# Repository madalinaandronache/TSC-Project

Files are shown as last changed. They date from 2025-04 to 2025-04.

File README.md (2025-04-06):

# OpenBook - E-book Reader Open-Source

Student: Andronache Madalina-Georgiana
Grupa: 332CC

Urmatorul fisier contine informatii despre rezolvarea cerintelor
propuse.

Cuprins:

0. Descrierea cerintelor
1. Diagrama bloc
2. BOM - Bill of Materials
3. Functionalitatea hardware
4. Pini utilizați pe ESP32-C6 și justificare
5. Observatii

## 0. Descrierea cerintelor

OpenBook este un e-book reader open-source, conceput să fie ieftin, compact și ușor de produs. 
Acest proiect este realizat în cadrul unui start-up educațional, iar scopul este dezvoltarea unui 
dispozitiv complet funcțional, pornind de la specificațiile sistemului până la fișierele de fabricație.

## 1. Diagrama bloc

Hardware Diagram

## 2. BOM - Bill of Materials

| Device | Value | Check_Price | Datasheet |
|---|---|---|---|
| ADAFRUIT_LEDCHIP-LED0603 | - | [Link](https://www.snapeda.com/parts/KP-1608SURCK/Kingbright/view-part/?ref=search&t=LED%200603) | [Link](https://www.snapeda.com/parts/KP-1608SURCK/Kingbright/datasheet/) |
| SJ | - | [Link](https://grabcad.com/library/solder-jumpers-1) | - |
| EAGLE-LTSPICE_C | 0.1uF/50V | [Link](https://componentsearchengine.com/part-view/CC0402MRX5R5BB106/YAGEO) | [Link](https://componentsearchengine.com/Datasheets/2/CC0402MRX5R5BB106.pdf) |
| ESP32_WROVER_EAGLE-LTSPICE_R | 0.47 | [Link](https://componentsearchengine.com/part-view/R0402%201%25%20100%20K%20(RC0402FR-07100KL)/YAGEO) | [Link](https://www.yageo.com/upload/media/product/products/datasheet/rchip/PYu-RC_Group_51_RoHS_L_12.pdf) |
| ESP32_WROVER_EAGLE-LTSPICE_R | 100K | [Link](https://componentsearchengine.com/part-view/R0402%201%25%20100%20K%20(RC0402FR-07100KL)/YAGEO) | [Link](https://www.yageo.com/upload/media/product/products/datasheet/rchip/PYu-RC_Group_51_RoHS_L_12.pdf) |
| EAGLE-LTSPICE_C | 100nF | [Link](https://componentsearchengine.com/part-view/CC0402MRX5R5BB106/YAGEO) | [Link](https://componentsearchengine.com/Datasheets/2/CC0402MRX5R5BB106.pdf) |
| RCL_CPOL-EUCT3528 | 100uF TANT | [Link](https://www.snapeda.com/parts/TAJB475K025RNJ/AVX/view-part/?ref=dk&t=capacitor%203528&con_ref=None) | [Link](https://s3.amazonaws.com/snapeda/datasheet/TAJB475K025RNJ_AVX.pdf) |
| ESP32_WROVER_EAGLE-LTSPICE_R | 10K | [Link](https://componentsearchengine.com/part-view/R0402%201%25%20100%20K%20(RC0402FR-07100KL)/YAGEO) | [Link](https://www.yageo.com/upload/media/product/products/datasheet/rchip/PYu-RC_Group_51_RoHS_L_12.pdf) |
| EAGLE-LTSPICE_C | 10uF | [Link](https://componentsearchengine.com/part-view/CC0402MRX5R5BB106/YAGEO) | [Link](https://componentsearchengine.com/Datasheets/2/CC0402MRX5R5BB106.pdf) |
| 112A-TAAR-R03_ATTEND | 112A-TAAR-R03_ATTEND | [Link](https://store.comet.srl.ro/Catalogue/Product/43497/) | [Link](https://store.comet.bg/download-file.php?id=8824) |
| ESP32_WROVER_EAGLE-LTSPICE_R | 15 | [Link](https://componentsearchengine.com/part-view/R0402%201%25%20100%20K%20(RC0402FR-07100KL)/YAGEO) | [Link](https://www.yageo.com/upload/media/product/products/datasheet/rchip/PYu-RC_Group_51_RoHS_L_12.pdf) |
| EAGLE-LTSPICE_C | 1uF | [Link](https://componentsearchengine.com/part-view/CC0402MRX5R5BB106/YAGEO) | [Link](https://componentsearchengine.com/Datasheets/2/CC0402MRX5R5BB106.pdf) |
| EAGLE-LTSPICE_C | 1uF/50V | [Link](https://componentsearchengine.com/part-view/CC0402MRX5R5BB106/YAGEO) | [Link](https://componentsearchengine.com/Datasheets/2/CC0402MRX5R5BB106.pdf) |
| ESP32_WROVER_EAGLE-LTSPICE_R | 2.2 | [Link](https://componentsearchengine.com/part-view/R0402%201%25%20100%20K%20(RC0402FR-07100KL)/YAGEO) | [Link](https://www.yageo.com/upload/media/product/products/datasheet/rchip/PYu-RC_Group_51_RoHS_L_12.pdf) |
| ESP32_WROVER_EAGLE-LTSPICE_R | 200 | [Link](https://componentsearchengine.com/part-view/R0402%201%25%20100%20K%20(RC0402FR-07100KL)/YAGEO) | [Link](https://www.yageo.com/upload/media/product/products/datasheet/rchip/PYu-RC_Group_51_RoHS_L_12.pdf) |
| ESP32_WROVER_SPARKFUN-DISCRETESEMI_MOSFET_PCH-DMG2305UX-7 | 20V/4.2A/52m?/1.4W | [Link](https://componentsearchengine.com/part-view/DMG2305UX-7/Diodes%20Incorporated) | [Link](https://www.diodes.com//assets/Datasheets/DMG2305UX.pdf) |
| ESP32_WROVER_EAGLE-LTSPICE_R | 2K | [Link](https://componentsearchengine.com/part-view/R0402%201%25%20100%20K%20(RC0402FR-07100KL)/YAGEO) | [Link](https://www.yageo.com/upload/media/product/products/datasheet/rchip/PYu-RC_Group_51_RoHS_L_12.pdf) |
| EAGLE-LTSPICE_C | 4.7uF | [Link](https://componentsearchengine.com/part-view/CC0402MRX5R5BB106/YAGEO) | [Link](https://componentsearchengine.com/Datasheets/2/CC0402MRX5R5BB106.pdf) |
| EAGLE-LTSPICE_C | 4.7uF/25V | [Link](https://componentsearchengine.com/part-view/CC0402MRX5R5BB106/YAGEO) | [Link](https://componentsearchengine.com/Datasheets/2/CC0402MRX5R5BB106.pdf) |
| ESP32_WROVER_EAGLE-LTSPICE_R | 5k1 | [Link](https://componentsearchengine.com/part-view/R0402%201%25%20100%20K%20(RC0402FR-07100KL)/YAGEO) | [Link](https://www.yageo.com/upload/media/product/products/datasheet/rchip/PYu-RC_Group_51_RoHS_L_12.pdf) |
| 744043680IND_4828-WE-TPC_WRE | 68uH | [Link](https://ro.mouser.com/ProductDetail/Wurth-Elektronik/744043680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.) | [Link](https://www.we-online.com/components/products/datasheet/744043680.pdf) |
| BD5229G-TR | BD5229G-TR | [Link](https://componentsearchengine.com/part-view/BD5229G-TR/ROHM%20Semiconductor) | [Link](https://datasheet.datasheetarchive.com/originals/distributors/Datasheets_SAMA/f2b9741ef86007909f138d561a359946.pdf) |
| ESP32_WROVER_BME680_BME680 | BME688 | [Link](https://www.snapeda.com/parts/BME680/Bosch/view-part/?welcome=home) | [Link](https://www.snapeda.com/parts/BME680/Bosch%20Sensortec/datasheet/) |
| BUTTON_CUSYOMV1V2 | BUTTON_CUSYOMV1V2 | [Link](https://industry.panasonic.com/global/en/products/control/switch/light-touch/number/evqpuj02k) | [Link](https://industry.panasonic.com/global/en/downloads?tab=catalog&small_g_cd=203&part_no=EVQPUJ02K) |
| CPH3225A | CPH3225A | [Link](https://www.snapeda.com/parts/CPH3225A/Seiko+Instruments/view-part/?ref=eda) | [Link](https://www.snapeda.com/parts/CPH3225A/Seiko+Instruments/view-part/?ref=eda ) |
| DS3231SN# | DS3231SN# | [Link](https://www.snapeda.com/parts/DS3231SN%23/Analog+Devices/view-part/?ref=eda) | [Link](https://www.snapeda.com/parts/DS3231SN%23/Analog+Devices/view-part/?ref=eda) |
| ESP32-C6-WROOM-1-N8 | ESP32-C6-WROOM-1-N8 | [Link](https://www.snapeda.com/parts/ESP32-C6-WROOM-1-N8/Espressif+Systems/view-part/?ref=eda) | [Link](https://www.snapeda.com/parts/ESP32-C6-WROOM-1-N8/Espressif+Systems/view-part/?ref=eda) |
| ESP32C6_VARISTORCN1812 | ESP32C6_VARISTORCN1812 | [Link](https://www.mouser.co.uk/ProductDetail/EPCOS-TDK/B72520T0350K062?qs=dEfas%2FXlABIszF52uu7vrg%3D%3D) | [Link](https://www.tdk-electronics.tdk.com/inf/75/db/CTVS_14/Surge_protection_series.pdf) |
| ESP32_WROVER_SPARKFUN-IC-POWER_MCP73831 | ESP32_WROVER_SPARKFUN-IC-POWER_MCP73831 | [Link](https://ro.mouser.com/ProductDetail/Microchip-Technology/MCP73831T-2ACI-OT?qs=yUQqVecv4qvbBQBGbHx0Mw%3D%3D) | [Link](https://ro.mouser.com/datasheet/2/268/MCP73831_Family_Data_Sheet_DS20001984H-3441711.pdf) |
| FH34SRJ-24S-0.5SH_99_ | FH34SRJ-24S-0.5SH_99_ | [Link](https://componentsearchengine.com/part-view/FH34SRJ-24S-0.5SH(99)/Hirose) | [Link](https://www.hirose.com/en/product/document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) |
| MAX17048G+T10 | MAX17048G+T10 | [Link](https://www.snapeda.com/parts/MAX17048G+T10/Analog+Devices/view-part/?ref=eda) | [Link](https://www.snapeda.com/parts/MAX17048G+T10/Analog+Devices/view-part/?ref=eda) |
| MBR0530. | MBR0530. | [Link](https://www.snapeda.com/parts/MBR0530/Onsemi/view-part/?ref=eda) | [Link](https://www.snapeda.com/parts/MBR0530/ON%20Semiconductor/datasheet/) |
| PGB1010603MR. | PGB1010603MR. | [Link](https://www.snapeda.com/parts/PGB1010603MR/Littelfuse/view-part/?ref=eda) | [Link](https://www.snapeda.com/parts/PGB1010603MR/Littelfuse%20Inc./datasheet/) |
| QWIIC_CONNECTORJS-1MM | QWIIC_RIGHT_ANGLE | [Link](https://www.digikey.lt/en/models/926710 ) | [Link](https://www.digikey.lt/en/models/926710) |
| SAMACSYS_PARTS_USB4110-GF-A | SAMACSYS_PARTS_USB4110-GF-A | [Link](https://componentsearchengine.com/part-view/USB4110-GF-A/GCT%20(GLOBAL%20CONNECTOR%20TECHNOLOGY)) | [Link](https://gct.co/files/drawings/usb4110.pdf) |
| ESP32_WROVER_AVX---SD0805S020S1R0_AVX_SD0805S020S1R0_0_0AVX_SD0805S020S1R0_0_0 | SD0805S020S1R0 | [Link](https://ro.mouser.com/ProductDetail/KYOCERA-AVX/SD0805S020S1R0?qs=jCA%252BPfw4LHbpkAoSnwrdjw%3D%3D) | [Link](http://datasheets.avx.com/schottky.pdf) |
| SI1308EDL-T1-GE3 | SI1308EDL-T1-GE3 | [Link](https://www.snapeda.com/parts/SI1308EDL-T1-GE3/Vishay+Siliconix/view-part/?ref=eda) | [Link](https://www.snapeda.com/parts/SI1308EDL-T1-GE3/Vishay+Siliconix/view-part/?ref=eda) |
| TPV1 | TPV1 | Custom made | - |
| USBLC6-2SC6Y | USBLC6-2SC6Y | [Link](https://www.snapeda.com/parts/USBLC6-2SC6Y/STMicroelectronics/view-part/?ref=eda) | [Link](https://www.snapeda.com/parts/USBLC6-2SC6Y/STMicroelectronics/view-part/?ref=eda) |
| W25Q512JVEIQ | W25Q512JVEIQ | [Link](https://www.snapeda.com/parts/W25Q512JVEIQ/Winbond+Electronics/view-part/?ref=eda) | [Link](https://www.snapeda.com/parts/W25Q512JVEIQ/Winbond+Electronics/view-part/?ref=eda) |
| XC6220A331MR-G | XC6220A331MR-G | [Link](https://componentsearchengine.com/part-view/XC6220A331MR-G/Torex) | [Link](https://product.torexsemi.com/system/files/series/xc6220.pdf) |

## 3. Functionalitatea hardware

Prezentam in detaliu functionalitatea hardware a device-ului:

| Nr. | Componentă |
|-----|---|
| 1 | Microcontroller – ESP32-C6-WROOM-1 |
| 2 | Afișaj E-Ink – Waveshare WSH-13187, 7.5” |
| 3 | Senzor Mediu – Bosch BME688 |
| 4 | Baterie și Management Energie |
| 5 | Butoane – 3x Tactile Switch |
| 6 | Port USB-C |
| 7 | Conector Qwiic / STEMMA QT (I²C) |
| 8 | Slot MicroSD – Attend 112A-TAAR-R03 |
| 9 | RTC – DS3231 |

### 3.1. Microcontroller – ESP32-C6-WROOM-1
- **Procesor:** 32-bit RISC-V @ 160MHz
- **Memorie:** 512KB SRAM + 8MB flash extern (W25Q512JVEIQ)
- **Conectivitate:** Wi-Fi 6 (802.11ax), Bluetooth 5 LE, USB 2.0 Full-Speed
- **Periferice:** SPI, I²C, UART, GPIO multiple
- **Consum:** <50µA în deep sleep, moduri low-power disponibile
- **Securitate:** Secure boot, criptare flash, criptografie hardware

### 3.2. Afișaj E-Ink – Waveshare WSH-13187, 7.5”
- **Rezoluție:** 800x480, monocrom
- **Interfață:** SPI (4-wire) + CS, DC, RST, BUSY
- **Consum:** 15–25mA în timpul refresh-ului, zero static
- **Motivație:** Consum aproape zero în mod static, ideal pentru e-readere

### 3.3. Senzor Mediu – Bosch BME688
- **Parametri:** Temperatură, Umiditate, Presiune, Calitate Aer (eCO2, TVOC)
- **Precizie:** ±1°C, ±3%, ±1 hPa
- **Interfață:** I²C (400kHz)
- **Consum:** 2.1µA standby, 3.6mA peak
- **Motivație:** Multi-senzor compact, ideal pentru feedback ambiental

### 3.4. Baterie și Management Energie
- **Tip:** Li-Po 3.7V, 2500mAh
- **Fuel Gauge:** MAX17048 (I²C)
- **Charging IC:** MCP73831 – încărcare 5V/1A prin USB-C
- **LDO:** 3.3V stabil pentru întreaga placă
- **Consum Total:**  
  - Activ: 100–150mA  
  - Deep Sleep: <50µA

### 3.5. Butoane – 3x Tactile Switch
- **Model:** Panasonic EVQ-Q2A03W
- **Conectare:** GPIO + debounce hardware (RC)
- **Funcții:** Navigare meniu, pagină înainte/înapoi, confirmare

### 3.6. Port USB-C
- **Rol:** Încărcare + transfer date (USB 2.0)
- **Protecții:** ESD + terminare corectă
- **Capabilități:** OTA updates prin Wi-Fi / firmware update prin USB

### 3.7. Conector Qwiic / STEMMA QT (I²C)
- **Pini:** VCC, GND, SDA, SCL
- **Utilitate:** Extensibilitate rapidă prin senzori/modul I²C

### 3.8. Slot MicroSD – Attend 112A-TAAR-R03
- **Funcție:** Stocare externă (ebooks, logs, firmware)
- **Interfață:** SPI

### 3.9. RTC – DS3231
- **Precizie:** ±2ppm
- **Interfață:** I²C
- **Backup:** Supercapacitor

---

### Comunicații & Interfețe

| Tip | Componente |
|---|---|
| **SPI** | E-Paper, Flash extern, SD Card (în mod SPI) |
| **I²C** | BME688, MAX17048, DS3231, Qwiic/Stemma |
| **USB** | Încărcare și transfer date prin USB-C |
| **GPIO**  | Butoane, semnale control afișaj, charging enable |

---

### Consum de Energie (Estimativ)

| Modul | Consum Tipic |
|---|---|
| ESP32-C6 activ | 80–100mA |
| E-Paper refresh | 15–25mA |
| BME688 activ | 3.6mA |
| MAX17048 | ~50µA |
| DS3231 (RTC) | 3.5mA / 1µA backup |
| Deep Sleep Total  | <50–100µA |

---

### Dimensiuni & Alte Detalii
- **Dimensiuni:** 175 x 114 x 10 mm
- **Greutate:** 250g
- **Material carcasă:** ABS sau policarbonat, design ergonomic
- **Display:** Montat cu decupaj integrat
- **Producție:** PCB 2-layer, ENIG, carcasă prin injecție

---

## 4. Pini utilizați pe ESP32-C6 și justificare

| Pin ESP32-C6 | Componentă / Semnal | De ce? |
|---|---|---|
| GPIO1 | I²C SDA (BME688, MAX17048, DS3231, Qwiic) | Linie partajată I²C – economisește pini și permite extinderea facilă |
| GPIO2 | I²C SCL (BME688, MAX17048, DS3231, Qwiic) | Clock I²C pentru toți senzorii și extensii Qwiic |
| GPIO5 | SPI MISO (E-Paper, Flash extern) | Linie comună de intrare date în SPI |
| GPIO6 | SPI MOSI (E-Paper, Flash extern) | Linie de ieșire date către e-paper și flash |
| GPIO7 | SPI CLK | Semnal de clock pentru magistrala SPI |
| GPIO8 | E-Paper CS | Selectează afișajul pe magistrala SPI |
| GPIO9 | E-Paper DC (Data/Command) | Comută între comandă și date către e-paper |
| GPIO10 | E-Paper RST | Reset hardware e-paper |
| GPIO11 | E-Paper BUSY | Pin de stare (ocupat/liber) de la display |
| GPIO12 | Button #1 | Intrare digitală pentru navigare pagină înainte |
| GPIO13 | Button #2 | Intrare digitală pentru navigare pagină înapoi |
| GPIO14 | Button #3 | Intrare digitală pentru selectare/opțiune |
| GPIO15 | MAX17048 ALERT (opțional) | Pin de alertă nivel scăzut baterie |
| GPIO16 | USB D+ (intern la USB PHY) | Linie USB 2.0 (fixă pe ESP32-C6) |
| GPIO17 | USB D- (intern la USB PHY) | Linie USB 2.0 (fixă pe ESP32-C6) |
| GPIO18 | LED Status (opțional) | Indicator pentru activitate Wi-Fi, charging, notificări |
| GPIO19 | SD Card CS | Selectare chip pentru card microSD (SPI) |
| GPIO20 | SD Card MISO | Citire date de pe card microSD |
| GPIO21 | SD Card MOSI | Scriere date pe card microSD |
| GPIO4 | SD Card CLK | Semnal de clock pentru card microSD (SPI) |

## 5. Observatii

Fun to make, dar mult prea solicitant. Realizat in aproximativ 60 h.

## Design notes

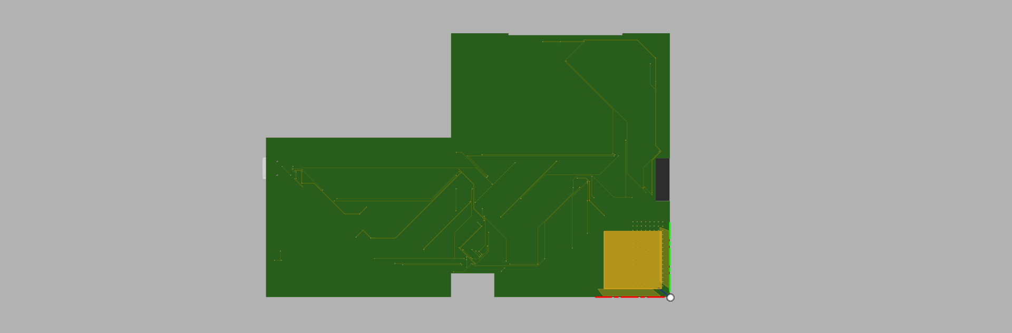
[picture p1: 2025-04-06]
Images/OpenBook_Bottom.png

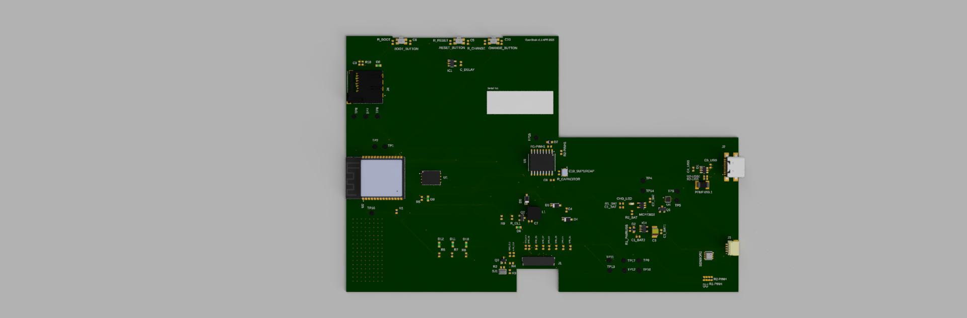
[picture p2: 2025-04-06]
Images/OpenBook_Top.JPEG

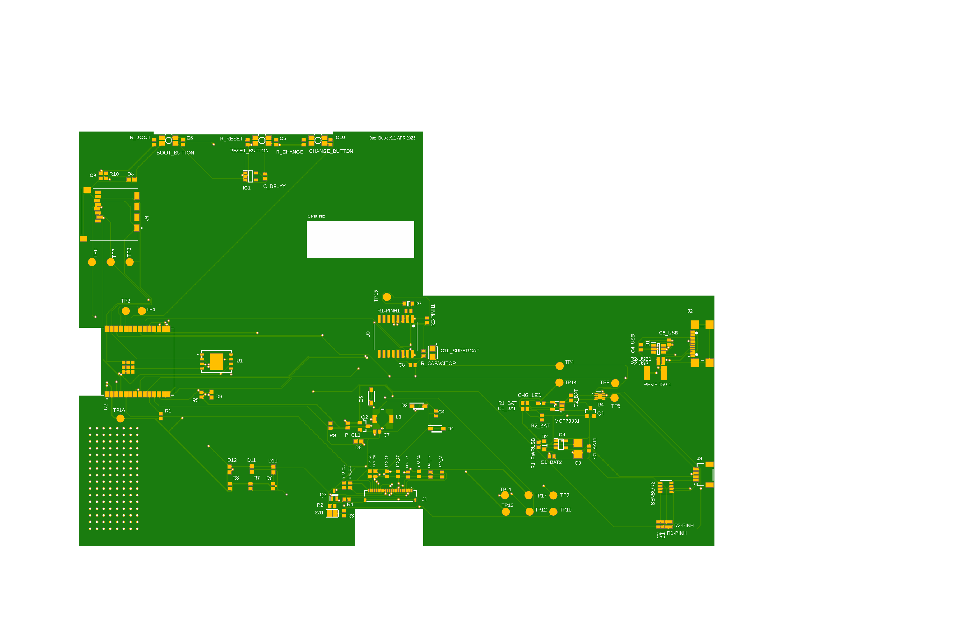
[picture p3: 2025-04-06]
Images/PCB-FrontView.png

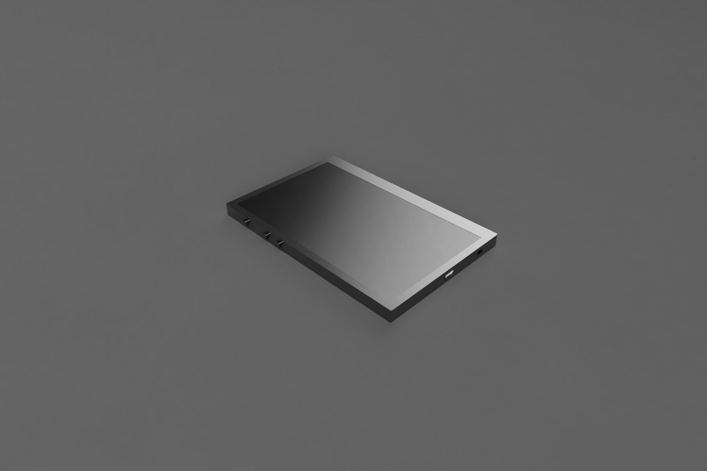
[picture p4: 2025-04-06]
Images/FullDevice_CustomView.jpg

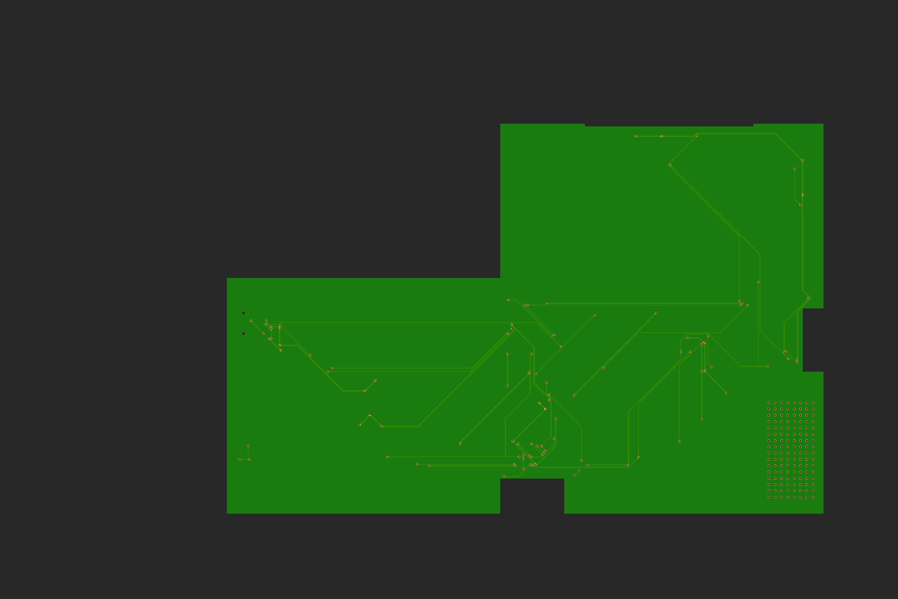
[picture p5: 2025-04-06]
Images/PCB-BottomView.png

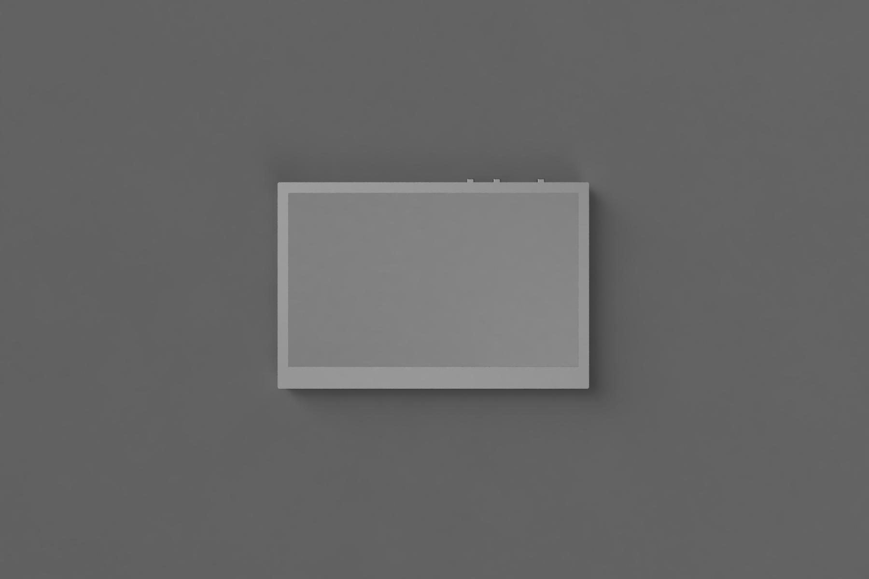
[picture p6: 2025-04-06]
Images/FullDevice_Front.jpg

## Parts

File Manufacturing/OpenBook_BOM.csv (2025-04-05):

Qty | Value | Device | Package | Parts | Description | ARROW_PART_NUMBER | ARROW_PRICE-STOCK | AVAILABILITY | CENTROID_NOT_SPECIFIED | CHECK_PRICES | COPYRIGHT | DATASHEET | DESCRIPTION | DIGIKEY_DESCRIPTION | DIGIKEY_PART_NUMBER | HEIGHT | LEAD_FREE | MANUFACTURER_NAME | MANUFACTURER_PART_NUMBER | MF | MFR_NAME | MOUSER_PART_NUMBER | MOUSER_PRICE-STOCK | MOUSER_TESTING_PART_NUMBER | MOUSER_TESTING_PRICE-STOCK | MP | MPN | PACKAGE | POPULARITY | PREFIX | PRICE | PROD_ID | PURCHASE-URL | ROHS | SNAPEDA_LINK | SPICEPREFIX | TEMPERATURE_RANGE_HIGH | TEMPERATURE_RANGE_LOW | VALUE
1 |  | ADAFRUIT_LEDCHIP-LED0603 | ADAFRUIT_CHIP-LED0603 | CHG_LED | LED |  |  |  |  | https://www.snapeda.com/parts/KP-1608SURCK/Kingbright/view-part/?ref=search&t=LED%200603 |  | https://www.snapeda.com/parts/KP-1608SURCK/Kingbright/datasheet/
1 |  | SJ | SJ | SJ1 | SMD solder JUMPER |  |  |  |  | https://grabcad.com/library/solder-jumpers-1 |  |  |  |  |  |  |  |  |  |  |  |  |  |  |  |  |  |  | 3
1 | 0.1uF/50V | EAGLE-LTSPICE_C | EAGLE-LTSPICE_C0402 | EPD_C5 | CAPACITOR, European symbol |  |  |  |  | https://componentsearchengine.com/part-view/CC0402MRX5R5BB106/YAGEO |  | https://componentsearchengine.com/Datasheets/2/CC0402MRX5R5BB106.pdf
1 | 0.47 | ESP32_WROVER_EAGLE-LTSPICE_R | ESP32_WROVER_EAGLE-LTSPICE_R0402 | R3 | RESISTOR, European symbol |  |  |  |  | https://componentsearchengine.com/part-view/R0402%201%25%20100%20K%20(RC0402FR-07100KL)/YAGEO |  | https://www.yageo.com/upload/media/product/products/datasheet/rchip/PYu-RC_Group_51_RoHS_L_12.pdf
1 | 100K | ESP32_WROVER_EAGLE-LTSPICE_R | ESP32_WROVER_EAGLE-LTSPICE_R0402 | R1_PWRUSB | RESISTOR, European symbol |  |  |  |  | https://componentsearchengine.com/part-view/R0402%201%25%20100%20K%20(RC0402FR-07100KL)/YAGEO |  | https://www.yageo.com/upload/media/product/products/datasheet/rchip/PYu-RC_Group_51_RoHS_L_12.pdf
8 | 100nF | EAGLE-LTSPICE_C | EAGLE-LTSPICE_C0402 | C1, C2, C4_USB, C6, C8, C9, C10, C_DELAY | CAPACITOR, European symbol |  |  |  |  | https://componentsearchengine.com/part-view/CC0402MRX5R5BB106/YAGEO |  | https://componentsearchengine.com/Datasheets/2/CC0402MRX5R5BB106.pdf
1 | 100uF TANT | RCL_CPOL-EUCT3528 | RCL_CT3528 | C3 | POLARIZED CAPACITOR, European symbol |  |  |  |  | https://www.snapeda.com/parts/TAJB475K025RNJ/AVX/view-part/?ref=dk&t=capacitor%203528&con_ref=None |  | https://s3.amazonaws.com/snapeda/datasheet/TAJB475K025RNJ_AVX.pdf |  |  |  |  |  |  |  |  |  |  |  |  |  |  |  |  | 0 |  |  |  |  |  |  | C
16 | 10K | ESP32_WROVER_EAGLE-LTSPICE_R | ESP32_WROVER_EAGLE-LTSPICE_R0402 | R1, R1-PINH, R1-PINH1, R2-PINH, R2-PINH1, R4, R5, R6, R7, R8, R9, R10, R_BOOT, R_CHANGE, R_CL1, R_RESET | RESISTOR, European symbol |  |  |  |  | https://componentsearchengine.com/part-view/R0402%201%25%20100%20K%20(RC0402FR-07100KL)/YAGEO |  | https://www.yageo.com/upload/media/product/products/datasheet/rchip/PYu-RC_Group_51_RoHS_L_12.pdf
1 | 10uF | EAGLE-LTSPICE_C | EAGLE-LTSPICE_C0402 | C7 | CAPACITOR, European symbol |  |  |  |  | https://componentsearchengine.com/part-view/CC0402MRX5R5BB106/YAGEO |  | https://componentsearchengine.com/Datasheets/2/CC0402MRX5R5BB106.pdf
1 | 112A-TAAR-R03_ATTEND | 112A-TAAR-R03_ATTEND | 112ATAARR03ATTEND | J4 | Micro SD Card Socket, Push-Push Type, Top Mount, SMT, H=1.83mm, 10u |  |  |  |  | https://store.comet.srl.ro/Catalogue/Product/43497/ |  | https://store.comet.bg/download-file.php?id=8824 | Micro SD Card Socket | Push-Push Type | Top Mount | SMT | H=1.83mm | 10u |  |  | 1.9mm |  | ATTEND | 112A-TAAR-R03 ATTEND
1 | 15 | ESP32_WROVER_EAGLE-LTSPICE_R | ESP32_WROVER_EAGLE-LTSPICE_R0402 | R_CAPACITOR | RESISTOR, European symbol |  |  |  |  | https://componentsearchengine.com/part-view/R0402%201%25%20100%20K%20(RC0402FR-07100KL)/YAGEO |  | https://www.yageo.com/upload/media/product/products/datasheet/rchip/PYu-RC_Group_51_RoHS_L_12.pdf
1 | 1uF | EAGLE-LTSPICE_C | EAGLE-LTSPICE_C0402 | C5 | CAPACITOR, European symbol |  |  |  |  | https://componentsearchengine.com/part-view/CC0402MRX5R5BB106/YAGEO |  | https://componentsearchengine.com/Datasheets/2/CC0402MRX5R5BB106.pdf
9 | 1uF/50V | EAGLE-LTSPICE_C | EAGLE-LTSPICE_C0402 | EPD_C1, EPD_C2, EPD_C6, EPD_C7, EPD_C8, EPD_C9, EPD_C10, EPD_C11, EPD_C12 | CAPACITOR, European symbol |  |  |  |  | https://componentsearchengine.com/part-view/CC0402MRX5R5BB106/YAGEO |  | https://componentsearchengine.com/Datasheets/2/CC0402MRX5R5BB106.pdf
1 | 2.2 | ESP32_WROVER_EAGLE-LTSPICE_R | ESP32_WROVER_EAGLE-LTSPICE_R0402 | R2 | RESISTOR, European symbol |  |  |  |  | https://componentsearchengine.com/part-view/R0402%201%25%20100%20K%20(RC0402FR-07100KL)/YAGEO |  | https://www.yageo.com/upload/media/product/products/datasheet/rchip/PYu-RC_Group_51_RoHS_L_12.pdf
1 | 200 | ESP32_WROVER_EAGLE-LTSPICE_R | ESP32_WROVER_EAGLE-LTSPICE_R0402 | R1_BAT | RESISTOR, European symbol |  |  |  |  | https://componentsearchengine.com/part-view/R0402%201%25%20100%20K%20(RC0402FR-07100KL)/YAGEO |  | https://www.yageo.com/upload/media/product/products/datasheet/rchip/PYu-RC_Group_51_RoHS_L_12.pdf
2 | 20V/4.2A/52m?/1.4W | ESP32_WROVER_SPARKFUN-DISCRETESEMI_MOSFET_PCH-DMG2305UX-7 | ESP32_WROVER_SPARKFUN-DISCRETESEMI_SOT23-3 | Q1, Q2 | P-channel MOSFETs |  |  |  |  | https://componentsearchengine.com/part-view/DMG2305UX-7/Diodes%20Incorporated |  | https://www.diodes.com//assets/Datasheets/DMG2305UX.pdf |  |  |  |  |  |  |  |  |  |  |  |  |  |  |  |  |  |  |  | TRAN-14388 |  |  |  |  |  |  | 20V/4.2A/52m?/1.4W
1 | 2K | ESP32_WROVER_EAGLE-LTSPICE_R | ESP32_WROVER_EAGLE-LTSPICE_R0402 | R2_BAT | RESISTOR, European symbol |  |  |  |  | https://componentsearchengine.com/part-view/R0402%201%25%20100%20K%20(RC0402FR-07100KL)/YAGEO |  | https://www.yageo.com/upload/media/product/products/datasheet/rchip/PYu-RC_Group_51_RoHS_L_12.pdf
5 | 4.7uF | EAGLE-LTSPICE_C | EAGLE-LTSPICE_C0402 | C1_BAT, C1_BAT1, C1_BAT2, C2_BAT, C5_USB | CAPACITOR, European symbol |  |  |  |  | https://componentsearchengine.com/part-view/CC0402MRX5R5BB106/YAGEO |  | https://componentsearchengine.com/Datasheets/2/CC0402MRX5R5BB106.pdf
1 | 4.7uF/25V | EAGLE-LTSPICE_C | EAGLE-LTSPICE_C0402 | C4 | CAPACITOR, European symbol |  |  |  |  | https://componentsearchengine.com/part-view/CC0402MRX5R5BB106/YAGEO |  | https://componentsearchengine.com/Datasheets/2/CC0402MRX5R5BB106.pdf
2 | 5k1 | ESP32_WROVER_EAGLE-LTSPICE_R | ESP32_WROVER_EAGLE-LTSPICE_R0402 | R2-USB, R2-USB1 | RESISTOR, European symbol |  |  |  |  | https://componentsearchengine.com/part-view/R0402%201%25%20100%20K%20(RC0402FR-07100KL)/YAGEO |  | https://www.yageo.com/upload/media/product/products/datasheet/rchip/PYu-RC_Group_51_RoHS_L_12.pdf
1 | 68uH | 744043680IND_4828-WE-TPC_WRE | IND_4828-WE-TPC_WRE | L1 |  |  |  |  |  | https://ro.mouser.com/ProductDetail/Wurth-Elektronik/744043680?qs=PGXP4M47uW6VkZq%252BkzjrHA%3D%3D | Copyright (C) 2024 Ultra Librarian. All rights reserved. | https://www.we-online.com/components/products/datasheet/744043680.pdf |  |  |  |  |  |  | 744043680 |  | Wurth Electronics
1 | BD5229G-TR | BD5229G-TR | SOT95P280X125-5N | IC1 | Voltage Detector with Adjustable Delay Time: CMOS processes are utilized to develop high precision, low current consumption CMOS reset ICs that allow arbitrary setting of the delay time. The extensive lineup includes both Nch Open Drain and CMOS output types in a wide range of detection voltages (from 2.3V to 6.0V, in 0.1V steps), enabling selection of the ideal solution based on customer requirements. In addition, the entire series is of course both lead-free and RoHS-compliant. |  |  |  |  | https://componentsearchengine.com/part-view/BD5229G-TR/ROHM%20Semiconductor |  | https://datasheet.datasheetarchive.com/originals/distributors/Datasheets_SAMA/f2b9741ef86007909f138d561a359946.pdf | Voltage Detector with Adjustable Delay Time: CMOS processes are utilized to develop high precision | low current consumption CMOS reset ICs that allow arbitrary setting of the delay time. The extensive lineup includes both Nch Open Drain and CMOS output types in a wide range of detection voltages (from 2.3V to 6.0V | in 0.1V steps) | enabling selection of the ideal solution based on customer requirements. In addition | the entire series is of course both lead-free and RoHS-compliant. |  |  | 1.25mm |  | ROHM Semiconductor | BD5229G-TR |  |  | 755-BD5229G-TR | https://www.mouser.co.uk/ProductDetail/ROHM-Semiconductor/BD5229G-TR?qs=4kLU8WoGk0vvnhrrYwdszw%3D%3D
1 | BME688 | ESP32_WROVER_BME680_BME680 | ESP32_WROVER_BME680_PSON80P300X300X100-8N | SENSOR2 | Integrated Environmental Unit |  |  | Unavailable |  | https://www.snapeda.com/parts/BME680/Bosch/view-part/?welcome=home |  | https://www.snapeda.com/parts/BME680/Bosch%20Sensortec/datasheet/ | Integrated Environmental Unit |  |  |  |  |  |  | Bosch Sensortec |  |  |  |  |  | BME680 |  | LGA-8 Bosch Tools |  |  | None
3 | BUTTON_CUSYOMV1V2 | BUTTON_CUSYOMV1V2 | MYBUTTON | BOOT_BUTTON, CHANGE_BUTTON, RESET_BUTTON |  |  |  |  |  | https://industry.panasonic.com/global/en/products/control/switch/light-touch/number/evqpuj02k |  | https://industry.panasonic.com/global/en/downloads?tab=catalog&small_g_cd=203&part_no=EVQPUJ02K
1 | CPH3225A | CPH3225A | CAPCP3225X100N | C10_SUPERCAP | Cap 0.011F 3.3V 1210 Flat Check availability |  |  | Not in stock |  | https://www.snapeda.com/parts/CPH3225A/Seiko+Instruments/view-part/?ref=eda |  | CPH3225A datasheet by | SnapMagic Search | 11 mF (EDLC) Supercapacitor 3.3 V 1210 (3225 Metric) - - |  |  |  |  |  |  | Seiko Instruments |  |  |  |  |  | CPH3225A |  | 1210 Seiko |  |  | None |  | https://www.snapeda.com/api/url_track_click_mouser/?unipart_id=562593&manufacturer=Seiko Instruments&part_name=CPH3225A&search_term=None |  | https://www.snapeda.com/parts/CPH3225A/Seiko+Instruments/view-part/?ref=snap
1 | DS3231SN# | DS3231SN# | SOIC127P1032X265-16N | U3 | Real Time Clock Serial 16-Pin SOIC W T/R Check availability |  |  | In Stock |  | https://www.snapeda.com/parts/DS3231SN%23/Analog+Devices/view-part/?ref=eda |  | DS3231SN# datasheet by | SnapMagic Search | Extremely Accurate I2C-Integrated RTC/TCXO/Crystal |  |  |  |  |  |  | Analog Devices |  |  |  |  |  | DS3231SN# |  | SOIC-16 Maxim |  |  | None |  | https://www.snapeda.com/api/url_track_click_mouser/?unipart_id=99048&manufacturer=Analog Devices&part_name=DS3231SN#&search_term=None |  | https://www.snapeda.com/parts/DS3231SN%23/Analog+Devices/view-part/?ref=snap
1 | ESP32-C6-WROOM-1-N8 | ESP32-C6-WROOM-1-N8 | XCVR_ESP32-C6-WROOM-1-N8 | U2 | Check availability |  |  | In Stock |  | https://www.snapeda.com/parts/ESP32-C6-WROOM-1-N8/Espressif+Systems/view-part/?ref=eda |  | ESP32-C6-WROOM-1-N8 datasheet by | SnapMagic Search | Multiprotocol Modules ESP32-C6 module | Wi-Fi 6 in 2.4 GHz band | Bluetooth 5 | Zigbee 3.0 and Thread. ESP34-WROOM Compatible - ENGINEERING SAMPLE |  |  |  |  |  |  | Espressif Systems |  |  |  |  |  | ESP32-C6-WROOM-1-N8 |  | None |  |  | None |  |  |  | https://www.snapeda.com/parts/ESP32-C6-WROOM-1-N8/Espressif+Systems/view-part/?ref=snap
1 | ESP32C6_VARISTORCN1812 | ESP32C6_VARISTORCN1812 | ESP32C6_VARISTOR_CT/CN1812 | PFMF.050.1 | VARISTOR |  |  |  |  | https://www.mouser.co.uk/ProductDetail/EPCOS-TDK/B72520T0350K062?qs=dEfas%2FXlABIszF52uu7vrg%3D%3D |  | https://www.tdk-electronics.tdk.com/inf/75/db/CTVS_14/Surge_protection_series.pdf |  |  |  |  |  |  |  |  |  |  |  |  |  |  |  |  | 0
1 | ESP32_WROVER_SPARKFUN-IC-POWER_MCP73831 | ESP32_WROVER_SPARKFUN-IC-POWER_MCP73831 | ESP32_WROVER_SPARKFUN-IC-POWER_SOT23-5 | MCP73831 | MCP73831T Li-Ion, Li-Pol Controller |  |  |  |  | https://ro.mouser.com/ProductDetail/Microchip-Technology/MCP73831T-2ACI-OT?qs=yUQqVecv4qvbBQBGbHx0Mw%3D%3D |  | https://ro.mouser.com/datasheet/2/268/MCP73831_Family_Data_Sheet_DS20001984H-3441711.pdf |  |  |  |  |  |  |  |  |  |  |  |  |  |  |  |  |  |  |  | IC-09995
1 | FH34SRJ-24S-0.5SH_99_ | FH34SRJ-24S-0.5SH_99_ | FH34SRJ24S05SH99 | J1 | (0.50mm) Surface Mount, Right Angle |  |  |  |  | https://componentsearchengine.com/part-view/FH34SRJ-24S-0.5SH(99)/Hirose |  | https://www.hirose.com/en/product/document?clcode=CL0580-1255-6-99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 | 24 Position FFC | FPC Connector Contacts | (0.50mm) Surface Mount | Right Angle |  |  | 1.1mm |  | Hirose | FH34SRJ-24S-0.5SH(99) |  |  | 798-FH34SRJ24S05SH99 | https://www.mouser.co.uk/ProductDetail/Hirose-Connector/FH34SRJ-24S-0.5SH99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
1 | MAX17048G+T10 | MAX17048G+T10 | SON50P200X200X80-9N | U4 | Check availability |  |  | In Stock |  | https://www.snapeda.com/parts/MAX17048G+T10/Analog+Devices/view-part/?ref=eda |  | MAX17048G+T10 datasheet by | SnapMagic Search | 3µA 1-Cell/2-Cell Fuel Gauge with ModelGauge |  |  |  |  |  |  | Analog Devices |  |  |  |  |  | MAX17048G+T10 |  | TDFN-8 Maxim |  |  | None |  | https://www.snapeda.com/api/url_track_click_mouser/?unipart_id=329239&manufacturer=Analog Devices&part_name=MAX17048G+T10&search_term=None |  | https://www.snapeda.com/parts/MAX17048G+T10/Analog+Devices/view-part/?ref=snap
3 | MBR0530. | MBR0530. | SOD3716X135N | D3, D4, D5 | ON SEMICONDUCTOR - MBR0530 - DIODE, SCHOTTKY, 0.5A, 30V, SOD-123 |  |  |  |  | https://www.snapeda.com/parts/MBR0530/Onsemi/view-part/?ref=eda |  | https://www.snapeda.com/parts/MBR0530/ON%20Semiconductor/datasheet/
6 | PGB1010603MR. | PGB1010603MR. | DIOC1608X36N | D6, D8, D9, D10, D11, D12 | Check availability |  |  |  |  | https://www.snapeda.com/parts/PGB1010603MR/Littelfuse/view-part/?ref=eda |  | https://www.snapeda.com/parts/PGB1010603MR/Littelfuse%20Inc./datasheet/
1 | QWIIC_RIGHT_ANGLE | QWIIC_CONNECTORJS-1MM | JST04_1MM_RA | J3 | SparkFun I2C Standard Qwiic Connector |  |  |  |  | SM04B-SRSS-TB EDA | CAD 3D Model Download | Digikey |  | https://www.digikey.lt/en/models/926710 |  |  |  |  |  |  |  |  |  |  |  |  |  |  |  |  |  |  |  | CONN-13694 |  |  |  |  |  |  | QWIIC_RIGHT_ANGLE
1 | SAMACSYS_PARTS_USB4110-GF-A | SAMACSYS_PARTS_USB4110-GF-A | SAMACSYS_PARTS_USB4110GFA | J2 | CONN USB 2.0 TYPE-C R/A SMT |  |  |  |  | https://componentsearchengine.com/part-view/USB4110-GF-A/GCT%20(GLOBAL%20CONNECTOR%20TECHNOLOGY) |  | https://gct.co/files/drawings/usb4110.pdf | CONN USB 2.0 TYPE-C R/A SMT |  |  | 3.26mm |  | GCT (GLOBAL CONNECTOR TECHNOLOGY) | USB4110-GF-A |  |  | 640-USB4110-GF-A | https://www.mouser.co.uk/ProductDetail/GCT/USB4110-GF-A?qs=KUoIvG%2F9IlYiZvIXQjyJeA%3D%3D
2 | SD0805S020S1R0 | ESP32_WROVER_AVX---SD0805S020S1R0_AVX_SD0805S020S1R0_0_0AVX_SD0805S020S1R0_0_0 | ESP32_WROVER_AVX---SD0805S020S1R0_AVX_SD0805S020S1R0_0 | D2, D7 | Schottky Barrier Rectifier Diode |  |  |  | No | https://ro.mouser.com/ProductDetail/KYOCERA-AVX/SD0805S020S1R0?qs=jCA%252BPfw4LHbpkAoSnwrdjw%3D%3D |  | http://datasheets.avx.com/schottky.pdf |  | DIODE SCHOTTKY 20V 1A 0805 | 478-7800-1-ND |  | yes |  |  | AVX |  | 581-SD0805S020S1R0 |  |  |  |  |  | 0805 (2012 metric) |  | D |  |  |  | yes |  |  | +125°C | -55°C
1 | SI1308EDL-T1-GE3 | SI1308EDL-T1-GE3 | SOT65P210X110-3N | Q3 | MOSFET N-Ch 30V 1.5A TrenchFET SC70 Vishay Si1308EDL-T1-GE3 N-channel MOSFET Transistor, 1.5 A, 30 V, 3-Pin SC-70 |  |  | In Stock |  | https://www.snapeda.com/parts/SI1308EDL-T1-GE3/Vishay+Siliconix/view-part/?ref=eda |  | SI1308EDL-T1-GE3 datasheet by | SnapMagic Search | Si1308EDL-T1-GE3 N-channel MOSFET Transistor | 1.5 A | 30 V | 3-Pin SC-70 | Siliconix / Vishay SI1308EDL-T1-GE3 |  |  |  |  |  |  | Vishay Siliconix |  |  |  |  |  | SI1308EDL-T1-GE3 |  | SOT-323 Vishay Semiconductor |  |  | None |  | https://www.snapeda.com/api/url_track_click_mouser/?unipart_id=274603&manufacturer=Vishay Siliconix&part_name=SI1308EDL-T1-GE3&search_term=None |  | https://www.snapeda.com/parts/SI1308EDL-T1-GE3/Vishay+Siliconix/view-part/?ref=snap
17 | TPV1 | TPV1 | TP20R | TP1, TP2, TP3, TP4, TP5, TP6, TP7, TP8, TP9, TP10, TP11, TP12, TP13, TP14, TP15, TP16, TP17 | Test pad |  |  |  |  | Custom made
1 | USBLC6-2SC6Y | USBLC6-2SC6Y | SOT95P280X145-6N | D1 | Low Cap. ESD Protection Auto SOT-23-6 STMicroelectronics USBLC6-2SC6Y, Dual Uni-Directional TVS Diode Array, 6-Pin SOT-23 |  |  | In Stock |  | https://www.snapeda.com/parts/USBLC6-2SC6Y/STMicroelectronics/view-part/?ref=eda |  | USBLC6-2SC6Y datasheet by | SnapMagic Search | 17V Clamp 5A (8/20µs) Ipp Tvs Diode Surface Mount SOT-23-6 |  |  |  |  |  |  | STMicroelectronics |  |  |  |  |  | USBLC6-2SC6Y |  | SOT-23-6 STMicroelectronics |  |  | None |  |  |  | https://www.snapeda.com/parts/USBLC6-2SC6Y/STMicroelectronics/view-part/?ref=snap
1 | W25Q512JVEIQ | W25Q512JVEIQ | SON127P600X800X80-9N | U1 | Check availability |  |  | In Stock |  | https://www.snapeda.com/parts/W25Q512JVEIQ/Winbond+Electronics/view-part/?ref=eda |  | W25Q512JVEIQ datasheet by | SnapMagic Search | FLASH - NOR Memory IC 512Mb (64M x 8) SPI - Quad I/O 133 MHz 8-WSON (8x6) |  |  |  |  |  |  | Winbond Electronics |  |  |  |  |  | W25Q512JVEIQ |  | Package |  |  | None |  |  |  | https://www.snapeda.com/parts/W25Q512JVEIQ/Winbond+Electronics/view-part/?ref=snap
1 | XC6220A331MR-G | XC6220A331MR-G | SOT95P280X120-5N | IC4 | LDO Voltage Regulators |  |  |  |  | https://componentsearchengine.com/part-view/XC6220A331MR-G/Torex |  | https://product.torexsemi.com/system/files/series/xc6220.pdf | LDO Voltage Regulators |  |  | 1.2mm |  | Torex | XC6220A331MR-G |  |  | 865-XC6220A331MR-G | https://www.mouser.co.uk/ProductDetail/Torex-Semiconductor/XC6220A331MR-G?qs=AsjdqWjXhJ8ZSWznL1J0gg%3D%3D

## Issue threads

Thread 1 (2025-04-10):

Schematic symbol mirror - USBLC6-2SC6Y

antocarazeanu, 2025-04-10:
În acest issue se semnalează o problemă în schematic:

Componenta  D1 `USBLC6-2SC6Y` are pinii poziționați invers față de așteptări.

### Problemă:
- Pinout-ul din schematic este oglindit (mirror) față de poziția fizică/corectă a componentului.

### Task-uri:
- [x] Corectare schematic - repoziționare pini corect (mirror).
- [x] Verificare conexiuni după modificare.

madalinaandronache, 2025-04-11:
Fixed this in fd966540122503bdc4b7a8e2cc7ca3894636e92b.

Closed 2025-04-11.

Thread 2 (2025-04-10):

GND plane gaps — via stitching needed

antocarazeanu, 2025-04-10:
Planul de masă (GND) nu acoperă complet placa de circuit imprimat, existând zone goale atât pe layer-ul Top cât și pe Bottom. Este necesară aplicarea unui via stitching pentru a lega planurile de masă și a asigura o acoperire completă.

- [x] via stiching

madalinaandronache, 2025-04-11:
I have fixed this in:  8d8131fcbc3de64a1332cbef8f37204b4e0134ad.

Closed 2025-04-11.

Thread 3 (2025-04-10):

Missing 3D model for C1 capacitor

antocarazeanu, 2025-04-10:
Componenta C1 nu are atașat un model 3D în proiectul PCB. Este necesară adăugarea modelului pentru o vizualizare corectă și pentru validarea mecanică a plăcii.

## Task-uri:
 - [x] Identificare model 3D corespunzător pentru C1

 - [x] Adăugare model 3D în footprint

 - [x] Verificare randare 3D în editorul PCB

madalinaandronache, 2025-04-11:
I have fixed this in: a1d4188.

Closed 2025-04-11.

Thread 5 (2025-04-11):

PCB Thickness Mismatch

antocarazeanu, 2025-04-11:
În specificațiile proiectului, grosimea plăcii PCB ar trebui să fie de 1.0mm, însă la tine este setata la 1.6mm . Această diferență poate afecta atât dimensiunile finale, cât și compatibilitatea cu carcasa sau alte componente mecanice. Este necesară corectarea înainte de plasarea comenzii finale.

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

### Task-rui:
- [x] Schimbă grosimea plăcii la **1.0mm** în preferințele PCB.
- [x] Actualizează modelul 3D al plăcii pentru a reflecta noua grosime.

madalinaandronache, 2025-04-11:
I've checked the current PCB stack-up, and the total thickness is approximately 1.07 mm (Top: 0.035 mm + Core: 1 mm + Bottom: 0.035 mm), which is close to the 1.0 mm spec.

The board fits properly into the enclosure, with no mechanical issues observed. Therefore, no further thickness adjustment is necessary.

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

Closed 2025-04-11.

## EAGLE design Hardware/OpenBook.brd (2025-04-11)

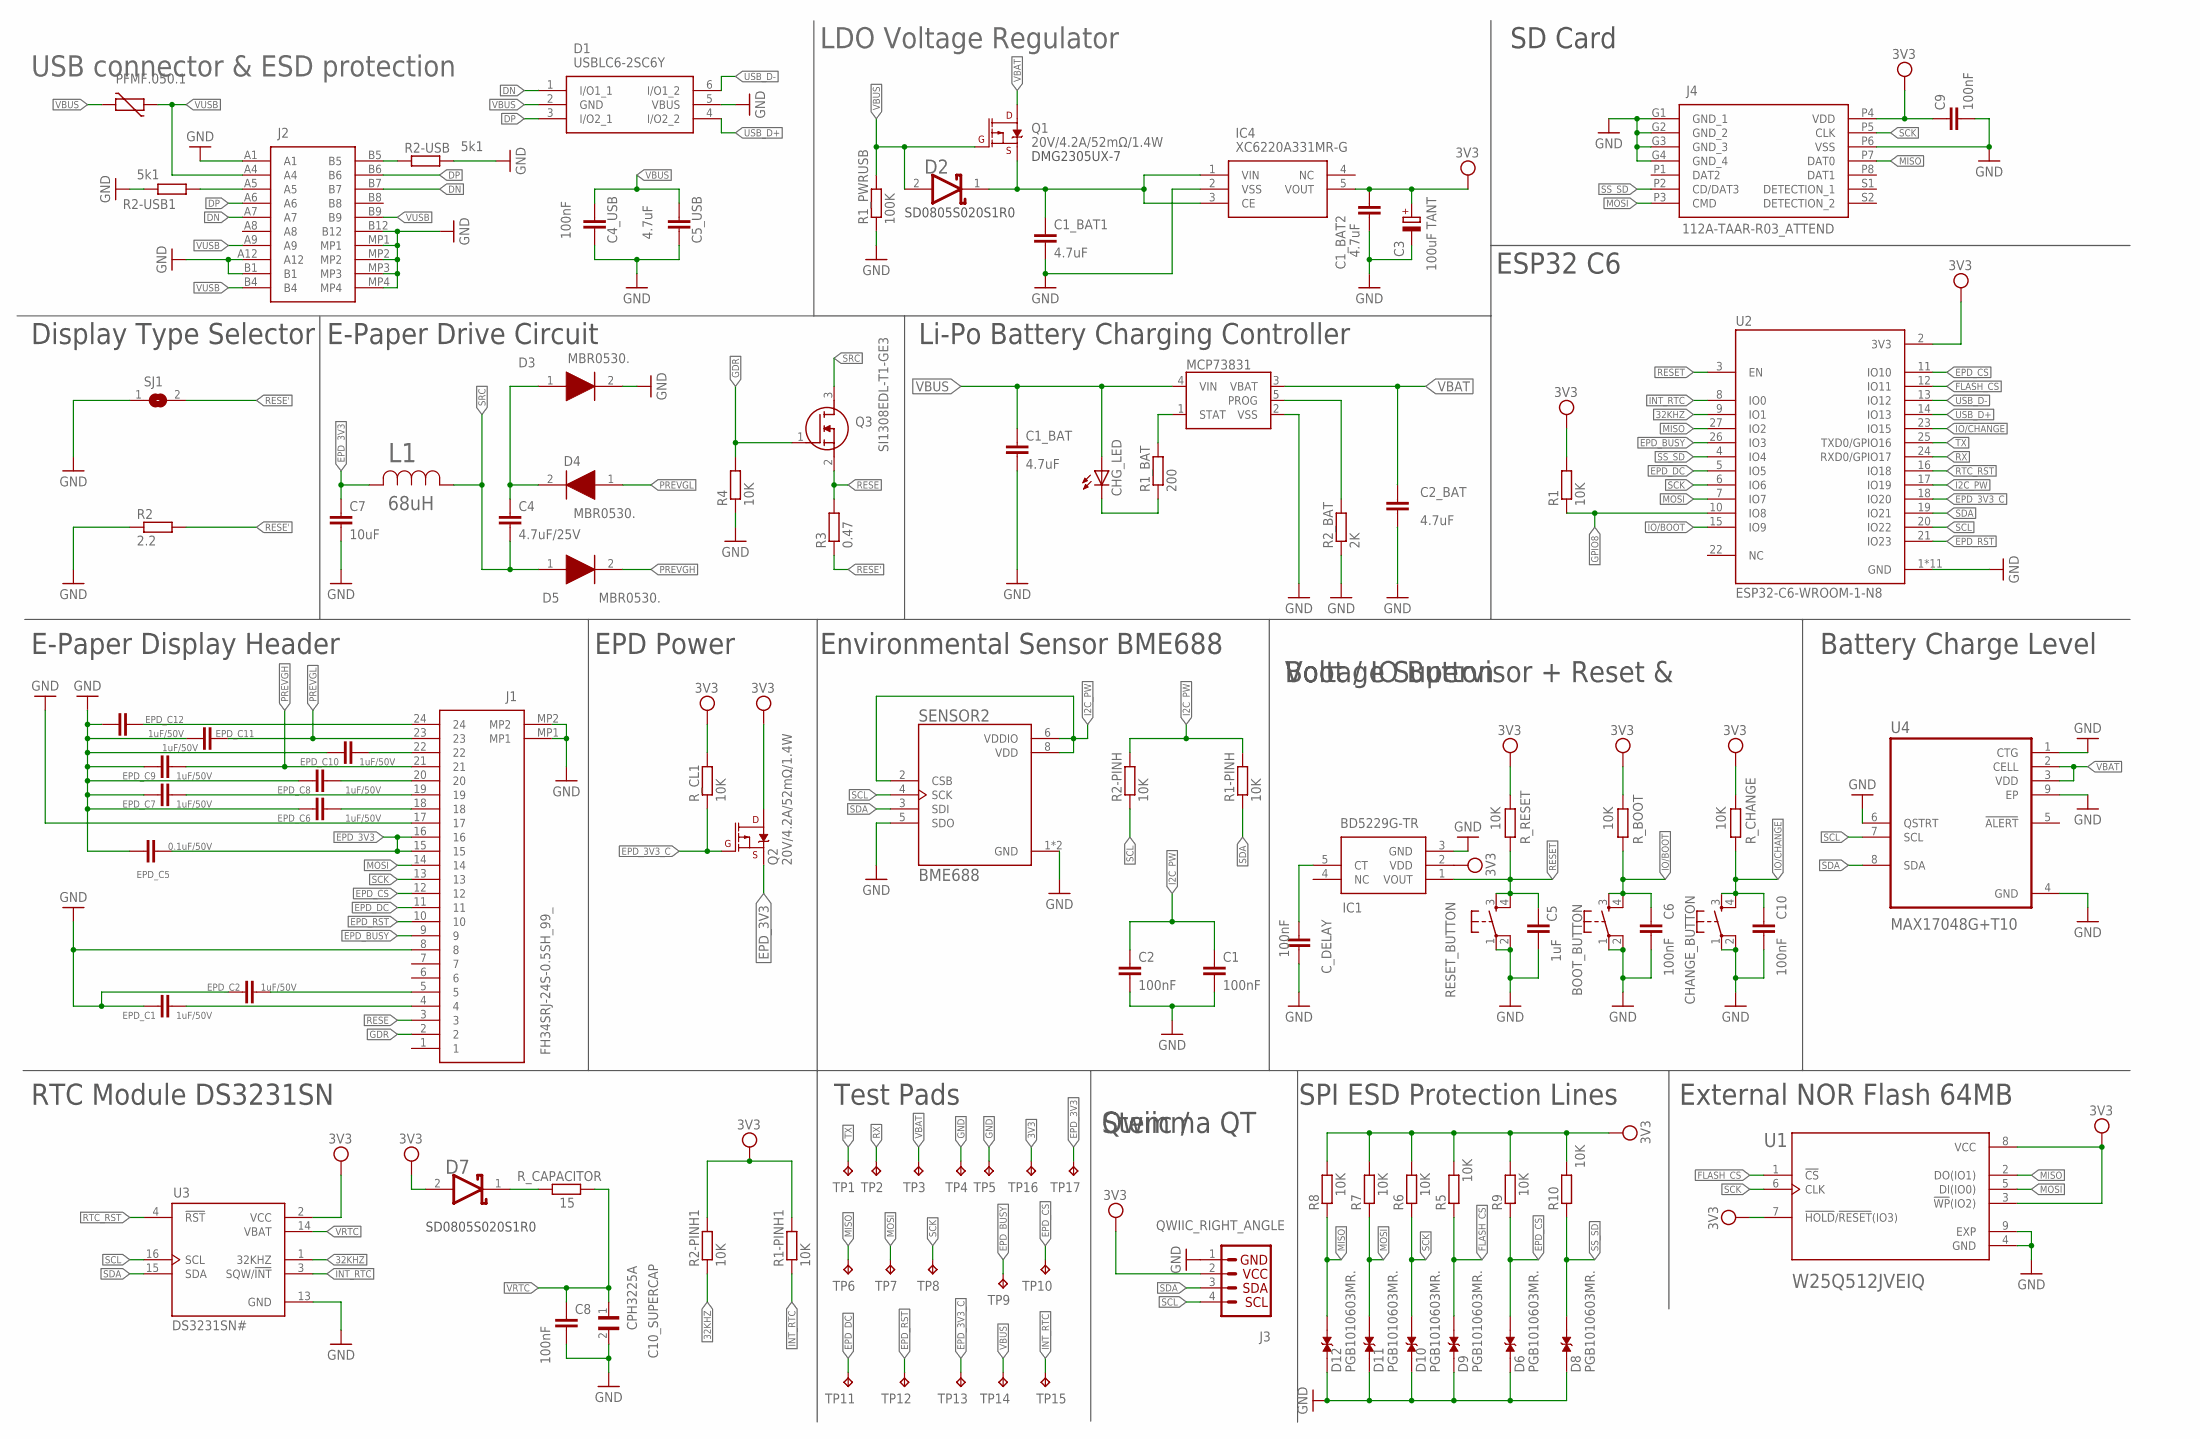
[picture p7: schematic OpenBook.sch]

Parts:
BOOT_BUTTON: BUTTON_CUSYOMV1V2; MYBUTTON
C1, C2, C4_USB, C6, C8, C9, C10: 100nF; EAGLE-LTSPICE_C0402
C1_BAT, C1_BAT1, C1_BAT2, C2_BAT, C5_USB: 4.7uF; EAGLE-LTSPICE_C0402
C3: 100uF TANT; RCL_CT3528
C4: 4.7uF/25V; EAGLE-LTSPICE_C0402
C5: 1uF; EAGLE-LTSPICE_C0402
C7: 10uF; EAGLE-LTSPICE_C0402
C10_SUPERCAP: CPH3225A; CAPCP3225X100N
CHANGE_BUTTON: BUTTON_CUSYOMV1V2; MYBUTTON
CHG_LED: ADAFRUIT_LEDCHIP-LED0603; ADAFRUIT_CHIP-LED0603
C_DELAY: 100nF; EAGLE-LTSPICE_C0402
D1: USBLC6-2SC6Y; SOT95P280X145-6N
D2, D7: SD0805S020S1R0; ESP32_WROVER_AVX---SD0805S020S1R0_AVX_SD0805S020S1R0_0
D3, D4, D5: MBR0530.; SOD3716X135N
D6, D8, D9, D10, D11, D12: PGB1010603MR.; DIOC1608X36N
EPD_C1, EPD_C2, EPD_C6, EPD_C7, EPD_C8, EPD_C9, EPD_C10, EPD_C11, EPD_C12: 1uF/50V; EAGLE-LTSPICE_C0402
EPD_C5: 0.1uF/50V; EAGLE-LTSPICE_C0402
IC1: BD5229G-TR; SOT95P280X125-5N
IC4: XC6220A331MR-G; SOT95P280X120-5N
J1: FH34SRJ-24S-0.5SH_99_; FH34SRJ24S05SH99
J2: SAMACSYS_PARTS_USB4110-GF-A; SAMACSYS_PARTS_USB4110GFA
J3: QWIIC_RIGHT_ANGLE; JST04_1MM_RA
J4: 112A-TAAR-R03_ATTEND; 112ATAARR03ATTEND
L1: 68uH; IND_4828-WE-TPC_WRE
MCP73831: ESP32_WROVER_SPARKFUN-IC-POWER_MCP73831; ESP32_WROVER_SPARKFUN-IC-POWER_SOT23-5
PFMF.050.1: ESP32C6_VARISTORCN1812; ESP32C6_VARISTOR_CT/CN1812
Q1, Q2: 20V/4.2A/52mΩ/1.4W; ESP32_WROVER_SPARKFUN-DISCRETESEMI_SOT23-3
Q3: SI1308EDL-T1-GE3; SOT65P210X110-3N
R1, R1-PINH, R1-PINH1, R2-PINH, R2-PINH1, R4, R5, R6, R7, R8, R9, R10: 10K; ESP32_WROVER_EAGLE-LTSPICE_R0402
R1_BAT: 200; ESP32_WROVER_EAGLE-LTSPICE_R0402
R1_PWRUSB: 100K; ESP32_WROVER_EAGLE-LTSPICE_R0402
R2: 2.2; ESP32_WROVER_EAGLE-LTSPICE_R0402
R2-USB, R2-USB1: 5k1; ESP32_WROVER_EAGLE-LTSPICE_R0402
R2_BAT: 2K; ESP32_WROVER_EAGLE-LTSPICE_R0402
R3: 0.47; ESP32_WROVER_EAGLE-LTSPICE_R0402
RESET_BUTTON: BUTTON_CUSYOMV1V2; MYBUTTON
R_BOOT: 10K; ESP32_WROVER_EAGLE-LTSPICE_R0402
R_CAPACITOR: 15; ESP32_WROVER_EAGLE-LTSPICE_R0402
R_CHANGE: 10K; ESP32_WROVER_EAGLE-LTSPICE_R0402
R_CL1: 10K; ESP32_WROVER_EAGLE-LTSPICE_R0402
R_RESET: 10K; ESP32_WROVER_EAGLE-LTSPICE_R0402
SENSOR2: BME688; ESP32_WROVER_BME680_PSON80P300X300X100-8N
SJ1: SJ
TP1, TP2, TP3, TP4, TP5, TP6, TP7, TP8, TP9, TP10, TP11, TP12, TP13, TP14, TP15, TP16, TP17: TPV1; TP20R
U1: W25Q512JVEIQ; SON127P600X800X80-9N
U2: ESP32-C6-WROOM-1-N8; XCVR_ESP32-C6-WROOM-1-N8
U3: DS3231SN#; SOIC127P1032X265-16N
U4: MAX17048G+T10; SON50P200X200X80-9N

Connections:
3V3: C1_BAT2.1, C3.+, C9.1, D7.2 (ANODE), IC1.2 (VDD), IC4.5 (VOUT), J3.2, J4.P4 (VDD), Q2.3 (D), R1.2, R1-PINH1.2, R2-PINH1.2, R5.2, R6.2, R7.2, R8.2, R9.2, R10.2, R_BOOT.2, R_CHANGE.2, R_CL1.2, R_RESET.2, TP16.TP, U1.3 (!WP!(IO2)), U1.7 (!HOLD!/!RESET!(IO3)), U1.8 (VCC), U2.2 (3V3), U3.2 (VCC)
32KHZ: R2-PINH1.1, U2.9 (IO1), U3.1 (32KHZ)
DN: D1.1 (I/O1_1), J2.A7, J2.B7
DP: D1.3 (I/O2_1), J2.A6, J2.B6
EPD_3V3: C7.1, EPD_C5.2, J1.15, J1.16, L1.2, Q2.2 (S), TP17.TP
EPD_3V3_C: Q2.1 (G), R_CL1.1, TP13.TP, U2.18 (IO20)
EPD_BUSY: J1.9, TP9.TP, U2.26 (IO3)
EPD_CS: D6.2, J1.12, R9.1, TP10.TP, U2.11 (IO10)
EPD_DC: J1.11, TP11.TP, U2.5 (IO5)
EPD_RST: J1.10, TP12.TP, U2.21 (IO23)
FLASH_CS: D9.2, R5.1, U1.1 (!CS), U2.12 (IO11)
GDR: J1.2, Q3.1 (G), R4.2
GND: BOOT_BUTTON.1, BOOT_BUTTON.2, C1.2, C1_BAT.2, C1_BAT1.2, C1_BAT2.2, C2.2, C2_BAT.2, C3.-, C4_USB.2, C5.2, C5_USB.2, C6.2, C7.2, C8.2, C9.2, C10.2, C10_SUPERCAP.2, CHANGE_BUTTON.1, CHANGE_BUTTON.2, C_DELAY.2, D1.5 (VBUS), D3.2 (K), D6.1, D8.1, D9.1, D10.1, D11.1, D12.1, EPD_C1.1, EPD_C2.1, EPD_C5.1, EPD_C6.1, EPD_C7.1, EPD_C8.1, EPD_C9.1, EPD_C10.1, EPD_C11.1, EPD_C12.1, IC1.3 (GND), IC4.2 (VSS), J1.8, J1.17, J1.MP1, J1.MP2, J2.A1, J2.A12, J2.B1, J2.B12, J2.MP1, J2.MP2, J2.MP3, J2.MP4, J3.1, J4.G1 (GND_1), J4.G2 (GND_2), J4.G3 (GND_3), J4.G4 (GND_4), J4.P6 (VSS), MCP73831.2 (VSS), R1_PWRUSB.1, R2.1, R2-USB.2, R2-USB1.1, R2_BAT.1, R4.1, RESET_BUTTON.1, RESET_BUTTON.2, SENSOR2.1 (GND), SENSOR2.5 (SDO), SENSOR2.7 (GND), SJ1.1, TP4.TP, TP5.TP, U1.4 (GND), U1.9 (EXP), U2.1 (GND), U2.28 (GND), U2.29_1 (GND), U2.29_2 (GND), U2.29_3 (GND), U2.29_4 (GND), U2.29_5 (GND), U2.29_6 (GND), U2.29_7 (GND), U2.29_8 (GND), U2.29_9 (GND), U3.13 (GND), U4.1 (CTG), U4.4 (GND), U4.6 (QSTRT), U4.9 (EP)
GPIO8: R1.1, U2.10 (IO8)
I2C_PW: C1.1, C2.1, R1-PINH.2, R2-PINH.2, SENSOR2.2 (CSB), SENSOR2.6 (VDDIO), SENSOR2.8 (VDD), U2.17 (IO19)
INT_RTC: R1-PINH1.1, TP15.TP, U2.8 (IO0), U3.3 (SQW/!INT)
IO/BOOT: BOOT_BUTTON.3, BOOT_BUTTON.4, C6.1, R_BOOT.1, U2.15 (IO9)
IO/CHANGE: C10.1, CHANGE_BUTTON.3, CHANGE_BUTTON.4, R_CHANGE.1, U2.23 (IO15)
MISO: D12.2, J4.P7 (DAT0), R8.1, TP6.TP, U1.2 (DO(IO1)), U2.27 (IO2)
MOSI: D11.2, J1.14, J4.P3 (CMD), R7.1, TP7.TP, U1.5 (DI(IO0)), U2.7 (IO7)
unnamed: D7.1 (CATHODE), R_CAPACITOR.1
unnamed: J2.A5, R2-USB1.2
unnamed: J2.B5, R2-USB.1
unnamed: C4.1, D3.1 (A), D4.2 (K)
unnamed: C1_BAT1.1, D2.1 (CATHODE), IC4.1 (VIN), IC4.3 (CE), Q1.2 (S)
unnamed: MCP73831.1 (STAT), R1_BAT.2
unnamed: MCP73831.5 (PROG), R2_BAT.2
unnamed: C_DELAY.1, IC1.5 (CT)
unnamed: CHG_LED.C, R1_BAT.1
unnamed: EPD_C1.2, J1.4
unnamed: EPD_C2.2, J1.5
unnamed: EPD_C6.2, J1.18
unnamed: EPD_C7.2, J1.19
unnamed: EPD_C10.2, J1.22
unnamed: EPD_C8.2, J1.20
unnamed: EPD_C12.2, J1.24
PREVGH: D5.2 (K), EPD_C9.2, J1.21
PREVGL: D4.1 (A), EPD_C11.2, J1.23
RESE: J1.3, Q3.2 (S), R3.2
RESE': R2.2, R3.1, SJ1.2
RESET: C5.1, IC1.1 (VOUT), RESET_BUTTON.3, RESET_BUTTON.4, R_RESET.1, U2.3 (EN)
RTC_RST: U2.16 (IO18), U3.4 (!RST)
RX: TP2.TP, U2.24 (RXD0/GPIO17)
SCK: D10.2, J1.13, J4.P5 (CLK), R6.1, TP8.TP, U1.6 (CLK), U2.6 (IO6)
SCL: J3.4, R2-PINH.1, SENSOR2.4 (SCK), U2.20 (IO22), U3.16 (SCL), U4.7 (SCL)
SDA: J3.3, R1-PINH.1, SENSOR2.3 (SDI), U2.19 (IO21), U3.15 (SDA), U4.8 (SDA)
SRC: C4.2, D5.1 (A), L1.1, Q3.3 (D)
SS_SD: D8.2, J4.P2 (CD/DAT3), R10.1, U2.4 (IO4)
TX: TP1.TP, U2.25 (TXD0/GPIO16)
USB_D+: D1.4 (I/O2_2), U2.14 (IO13)
USB_D-: D1.6 (I/O1_2), U2.13 (IO12)
VBAT: C2_BAT.1, MCP73831.3 (VBAT), Q1.3 (D), TP3.TP, U4.2 (CELL), U4.3 (VDD)
VBUS: C1_BAT.1, C4_USB.1, C5_USB.1, CHG_LED.A, D1.2 (GND), D2.2 (ANODE), MCP73831.4 (VIN), PFMF.050.1.2, Q1.1 (G), R1_PWRUSB.2, TP14.TP
VRTC: C8.1, C10_SUPERCAP.1, R_CAPACITOR.2, U3.14 (VBAT)
VUSB: J2.A4, J2.A9, J2.B4, J2.B9, PFMF.050.1.1

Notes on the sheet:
USB connector & ESD protection
LDO Voltage Regulator
SD Card
Display Type Selector
E-Paper Drive Circuit
Li-Po Battery Charging Controller
ESP32 C6
E-Paper Display Header
EPD Power
Environmental Sensor BME688
Voltage Supervisor + Reset &
Boot / IO Button
Battery Charge Level
RTC Module DS3231SN
Test Pads
Qwiic /
Stemma QT
SPI ESD Protection Lines
External NOR Flash 64MB
SD0805S020S1R0
DMG2305UX-7

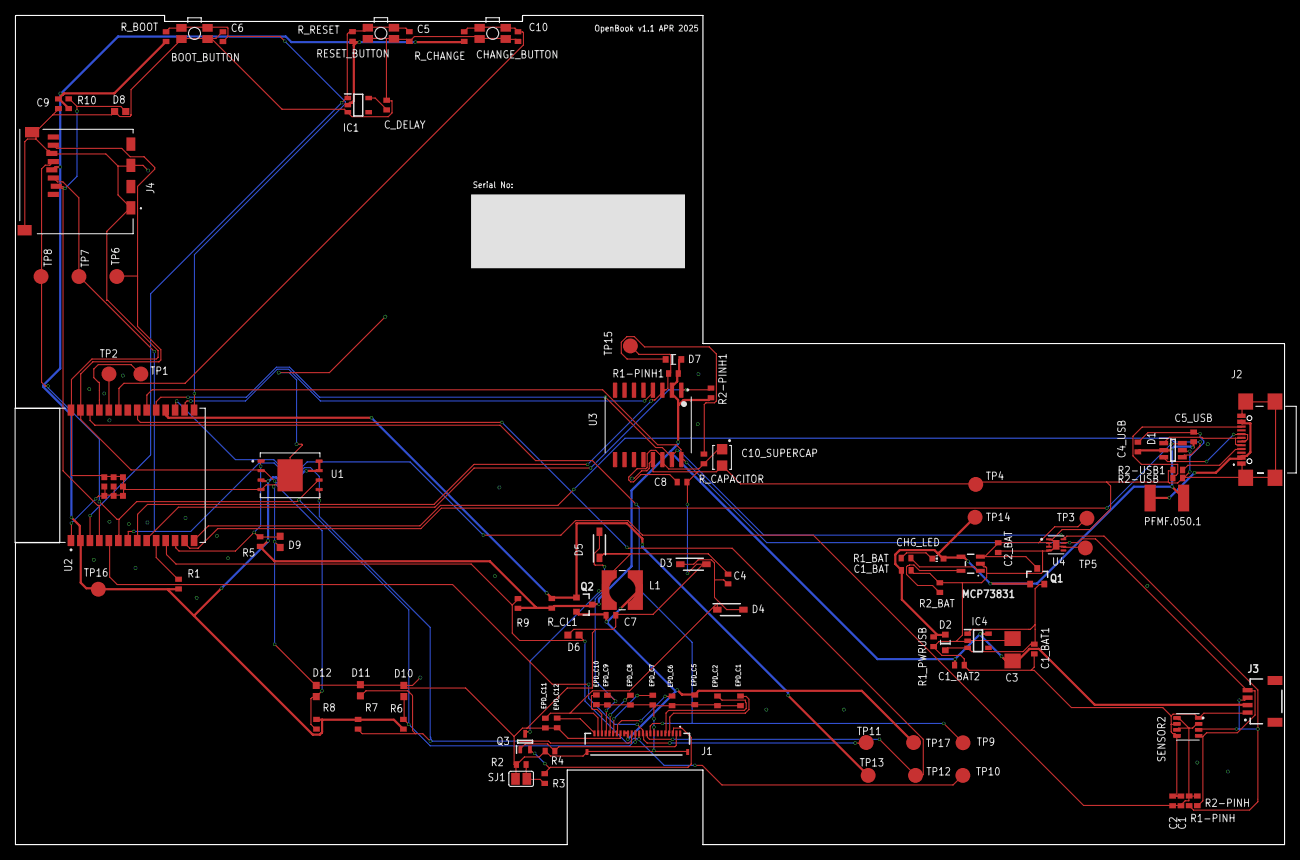
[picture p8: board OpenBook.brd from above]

Board: 2 copper layers, 170.2 x 111.2 mm, 103 parts (0 on the bottom side), 55 nets.

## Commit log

2025-04-05 Added BOM and PnP Files
    [OpenBook_BOM.csv, PnP_OpenBook_front.csv]
2025-04-05 Added the gerbers files
2025-04-06 Added the Hardware Parts
    [OpenBook.brd, OpenBook.sch]
2025-04-06 Updated the gerbers zip
2025-04-06 Added some renders of the board
2025-04-06 Added renders with the device
2025-04-06 Added views for PCB
2025-04-06 Updated gerbers
2025-04-11 Updated the schematic
    [OpenBook.brd, OpenBook.sch]
2025-04-11 Polygon pour updated
    [OpenBook.brd]

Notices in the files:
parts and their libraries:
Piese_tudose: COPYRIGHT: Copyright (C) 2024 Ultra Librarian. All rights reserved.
